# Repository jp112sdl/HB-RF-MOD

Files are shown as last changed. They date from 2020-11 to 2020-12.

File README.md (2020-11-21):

# HB-RF-MOD
Alternative Platine zum RPI-RF-MOD, um das Funkmodul "richtig herum" auf den Raspberry Pi aufsetzen zu können.

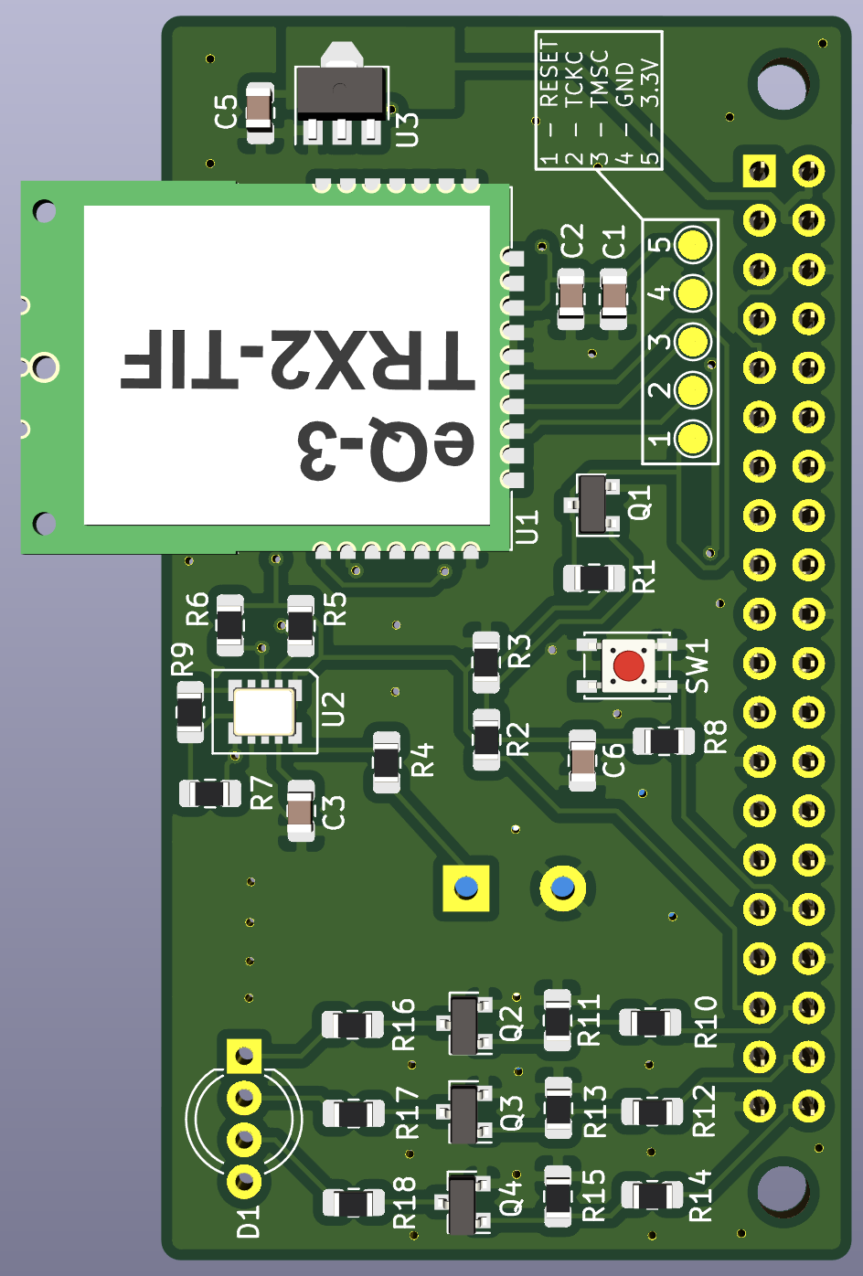
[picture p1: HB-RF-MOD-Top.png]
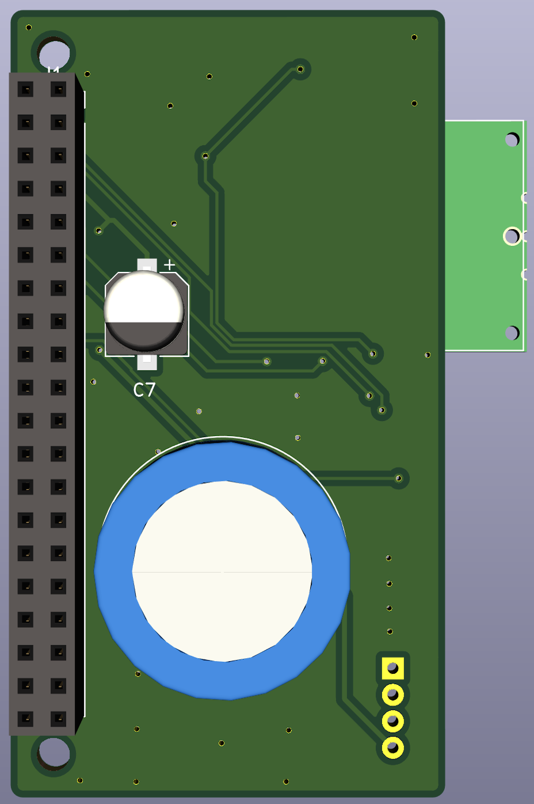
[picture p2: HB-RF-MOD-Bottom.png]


**19.11.2020 - die Platinen sind da** <br>
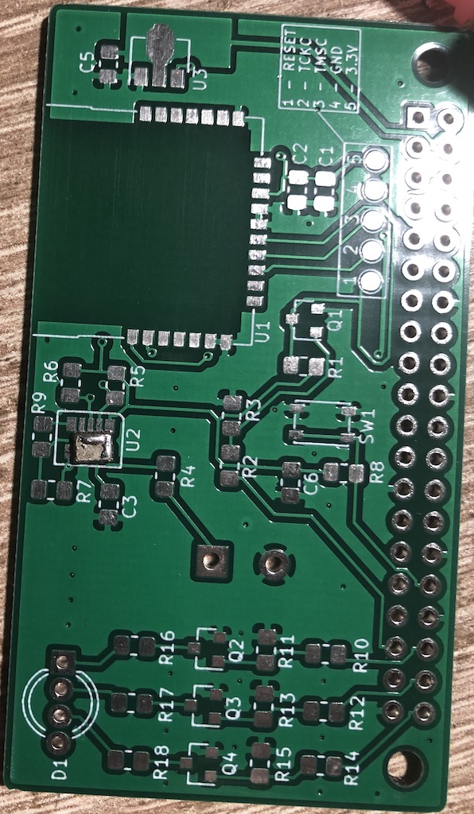
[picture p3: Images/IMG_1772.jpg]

<br/><br/>
**20.11.2020 - erster Aufbau und voller Erfolg!** :tada: <br/>
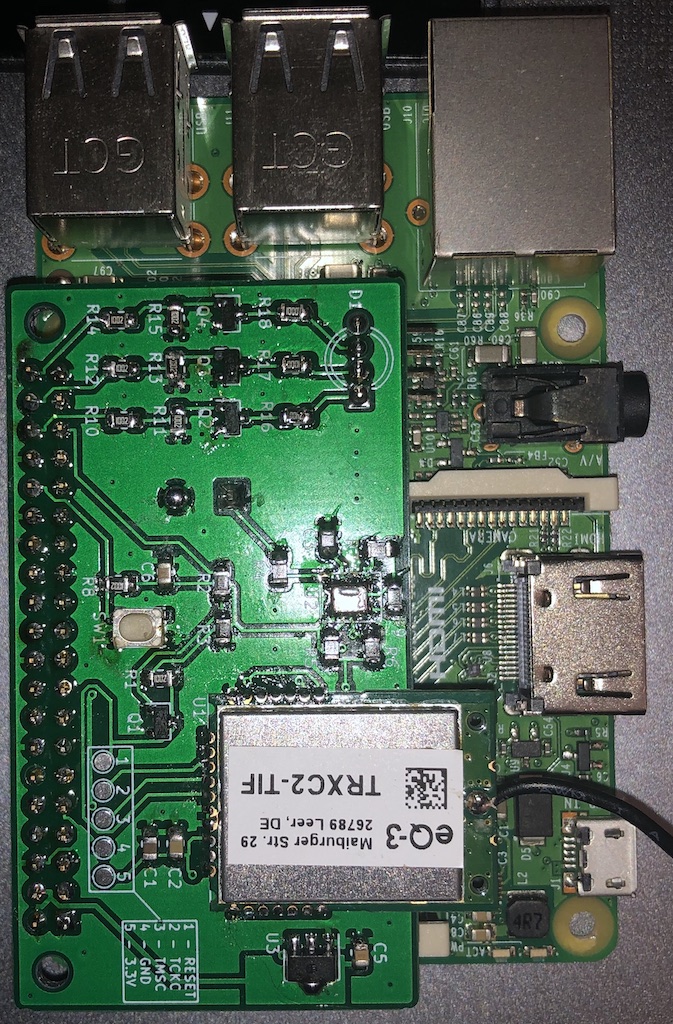
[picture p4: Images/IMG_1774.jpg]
<br/>
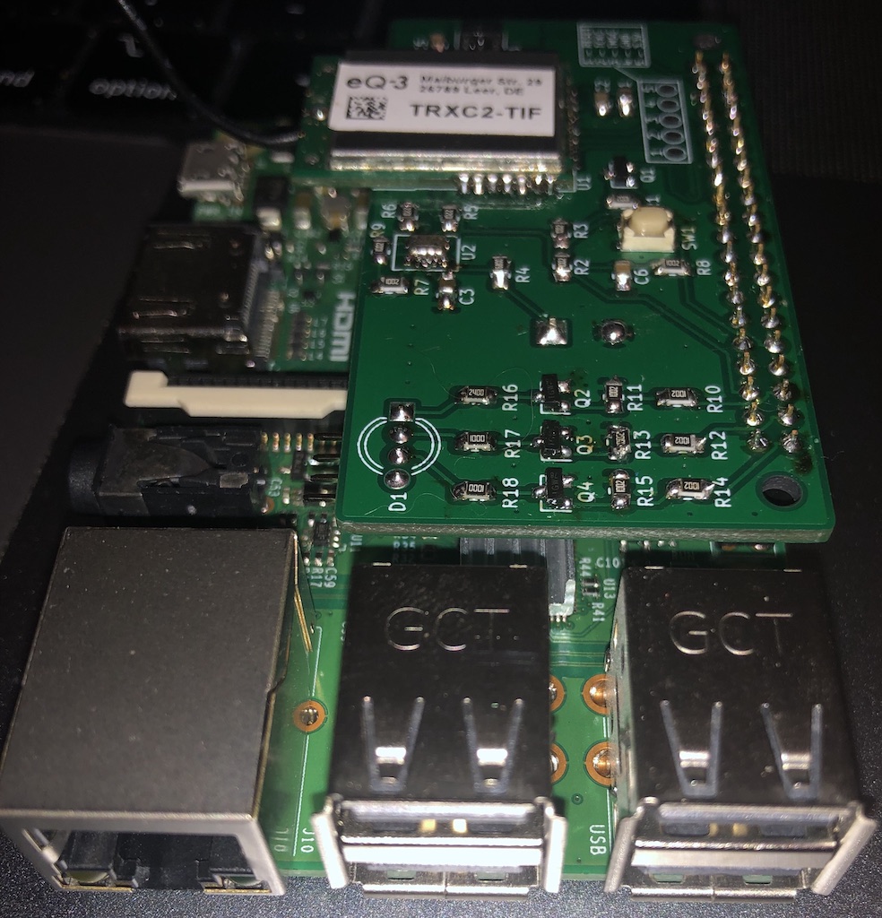
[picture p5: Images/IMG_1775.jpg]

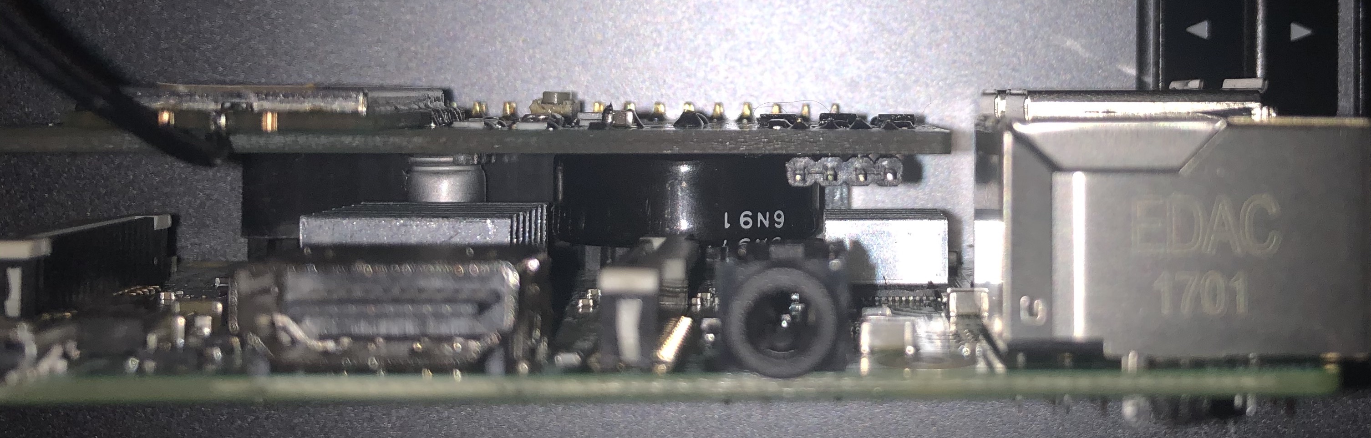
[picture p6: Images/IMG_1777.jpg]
<br/>
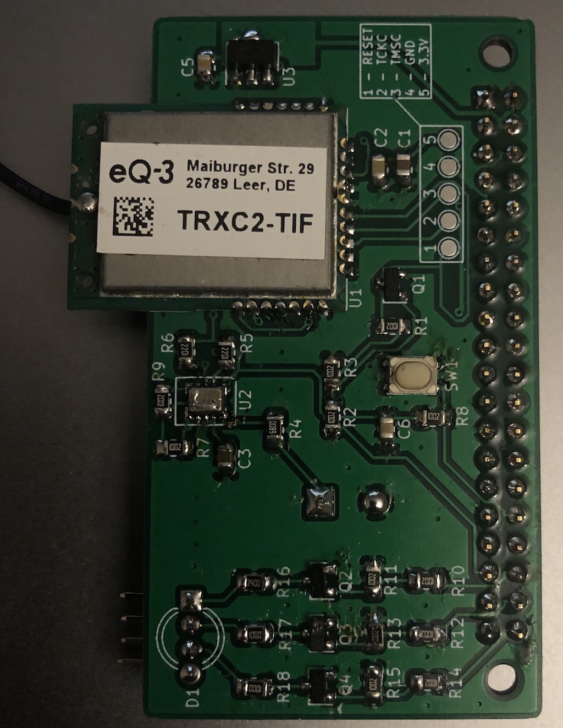
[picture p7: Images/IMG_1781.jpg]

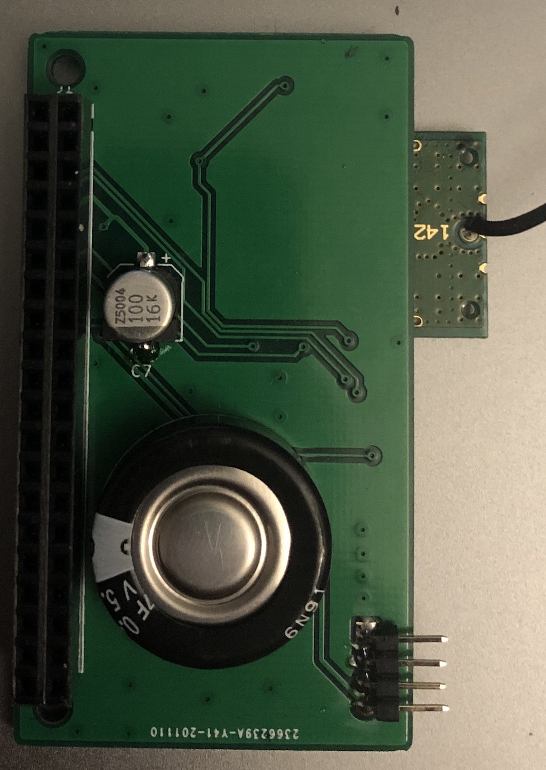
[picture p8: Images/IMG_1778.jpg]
<br/>

**21.11.2020 - Inbetriebnahme**<br/>
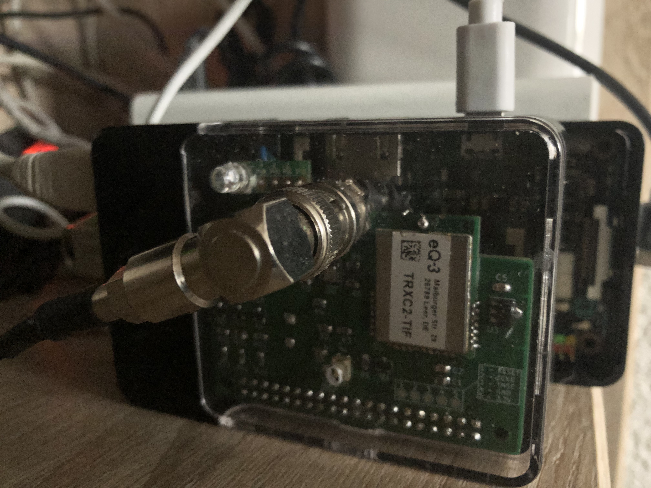
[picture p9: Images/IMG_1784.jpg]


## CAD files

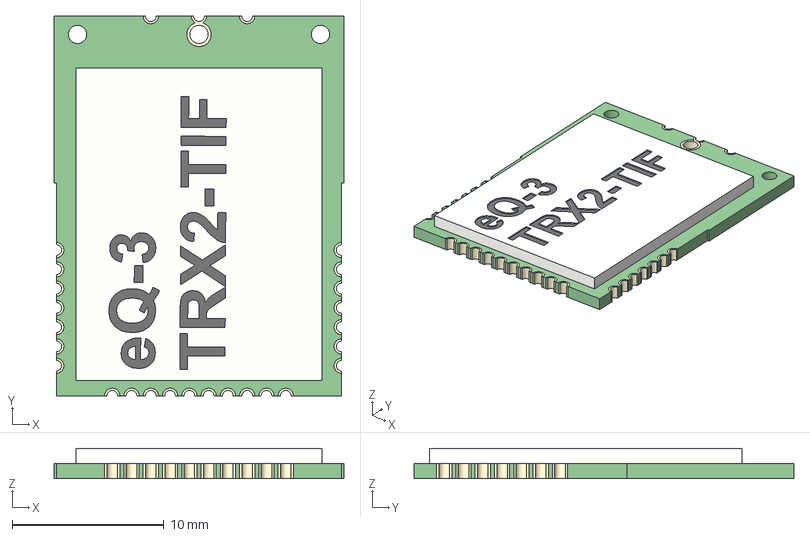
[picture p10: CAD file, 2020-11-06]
additional/TRX2-TIF.step
19.1 x 25.0 x 2.00 mm

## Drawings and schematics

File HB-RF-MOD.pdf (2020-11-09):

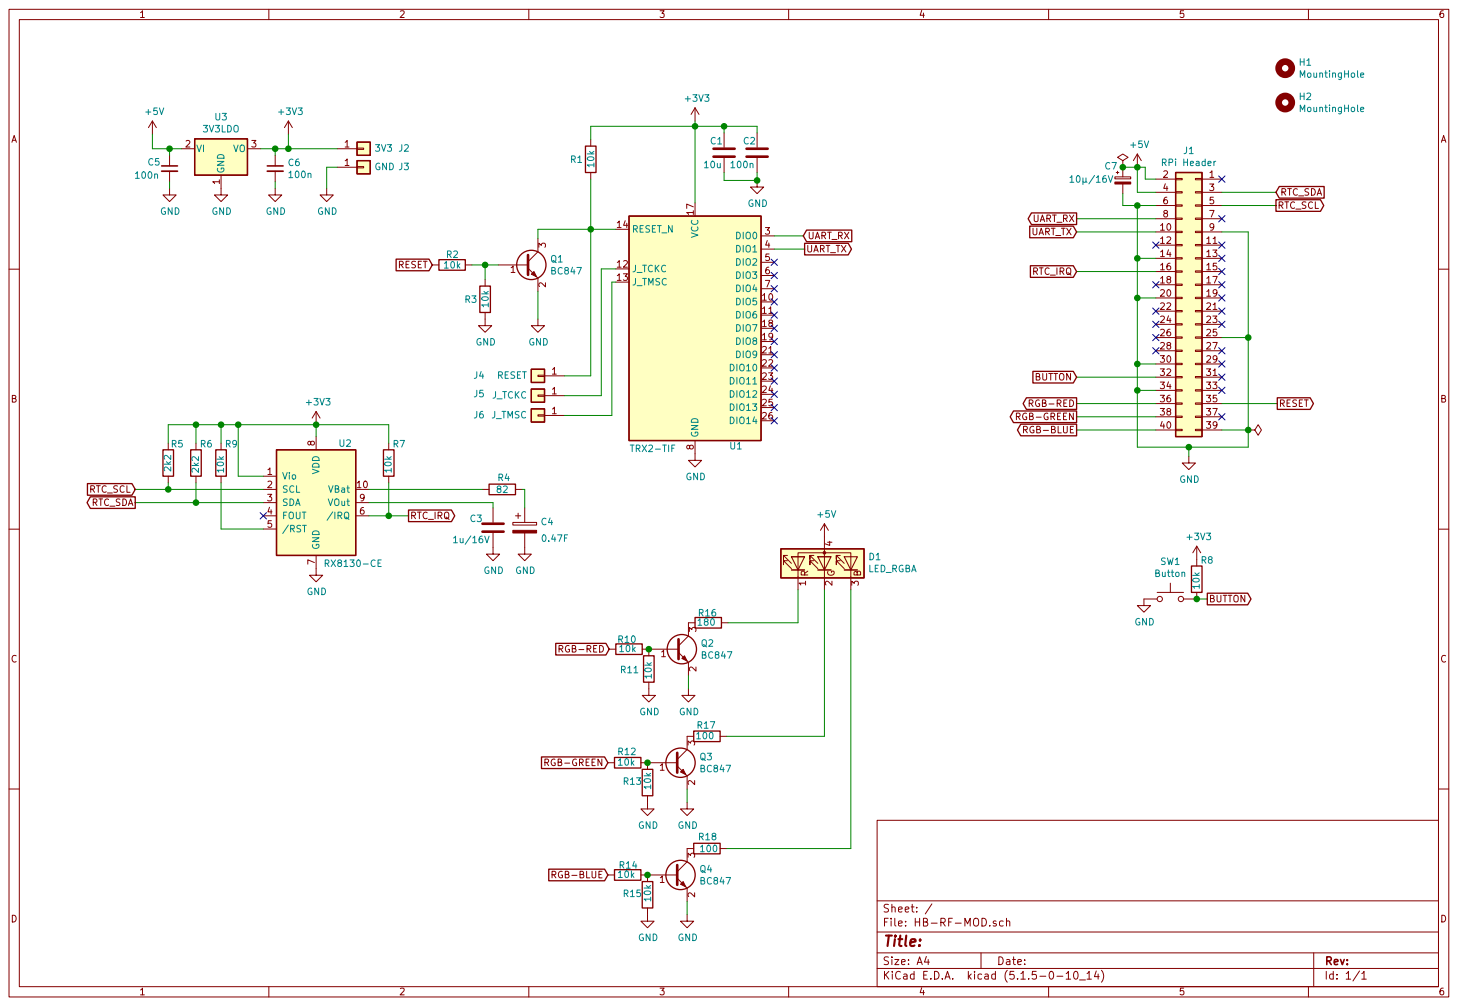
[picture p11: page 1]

Id: 1/1 Title: File: HB-RF-MOD.sch Sheet: /

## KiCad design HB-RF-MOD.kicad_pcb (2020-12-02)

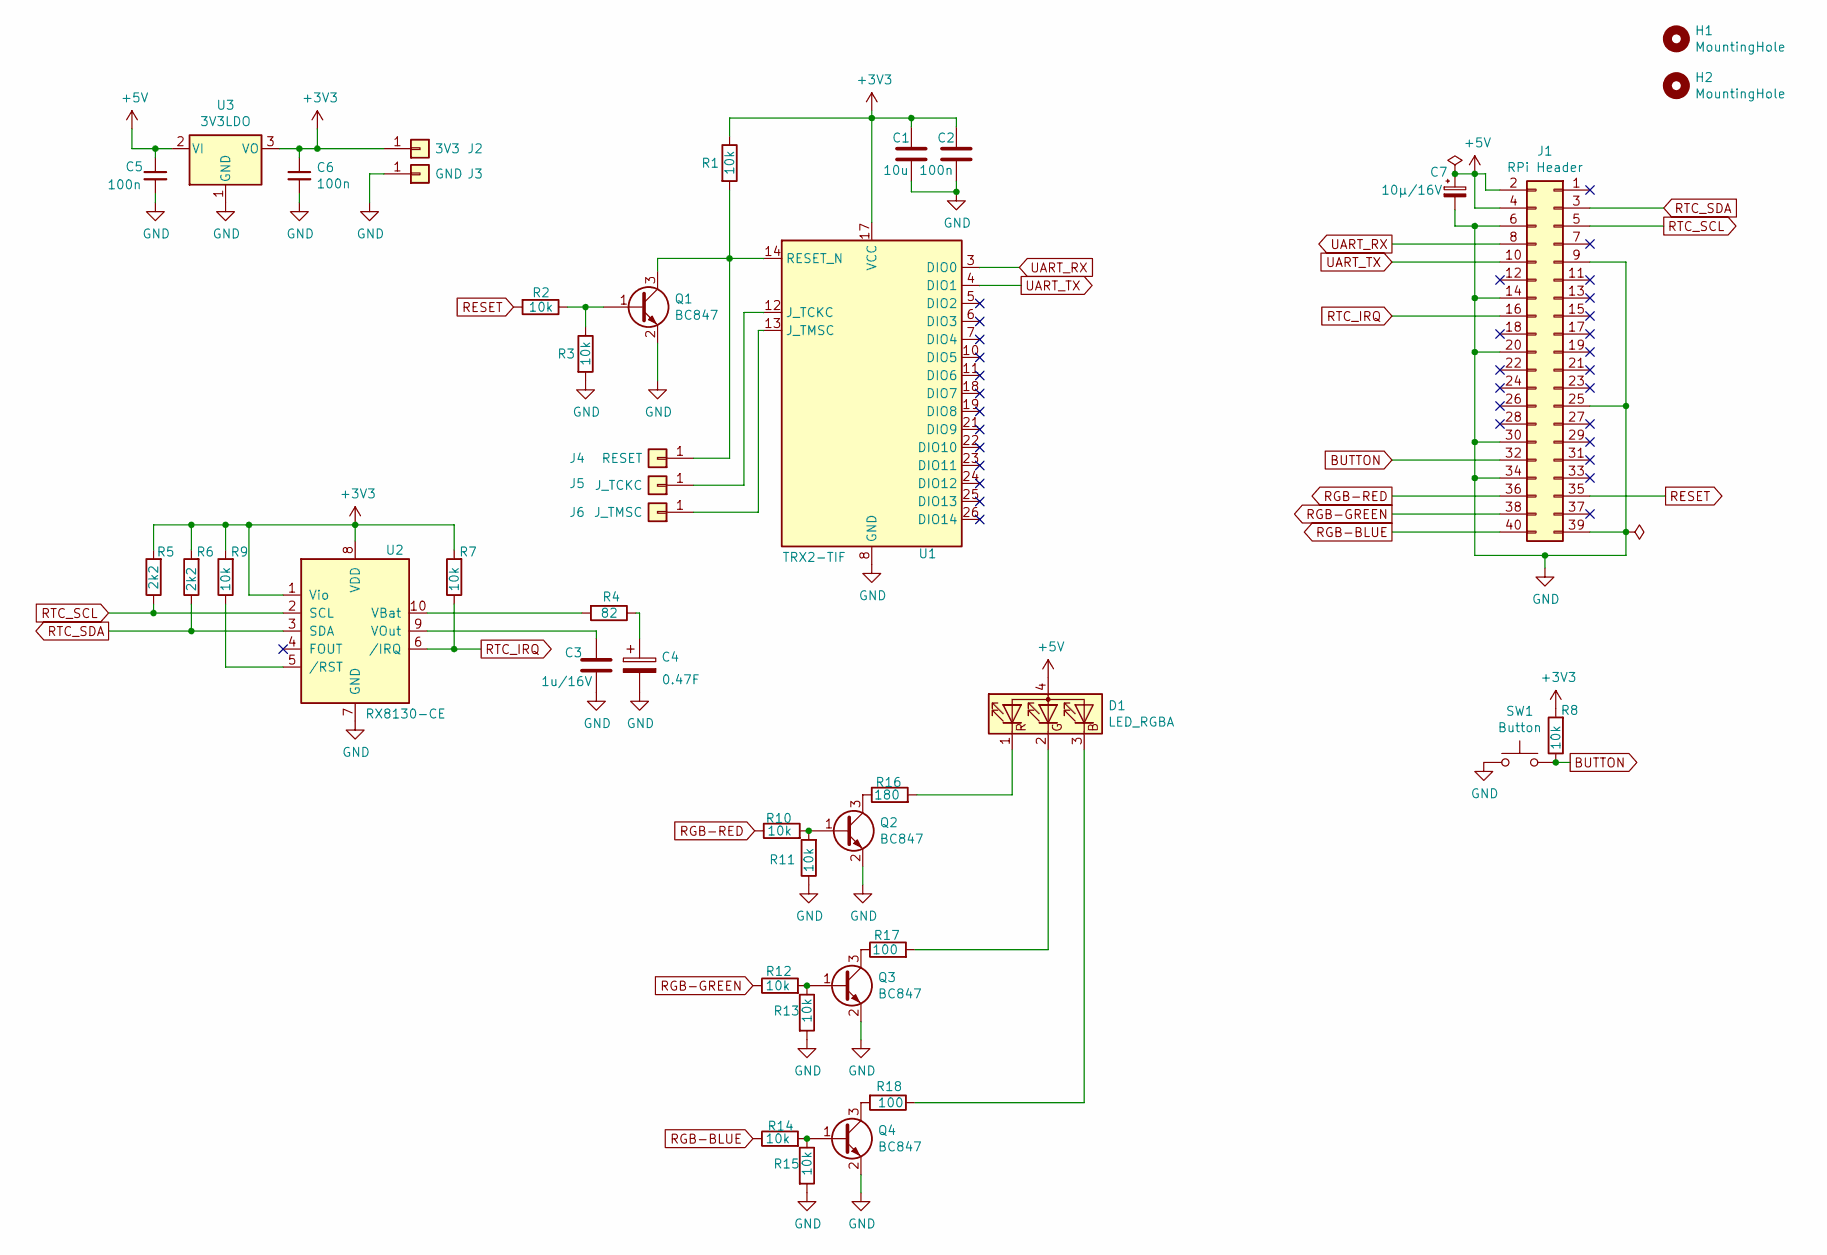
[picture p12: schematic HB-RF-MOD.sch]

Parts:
C1: 10u; C_0805_2012Metric_Pad1.15x1.40mm_HandSolder
C2, C5, C6: 100n; C_0805_2012Metric_Pad1.15x1.40mm_HandSolder
C3: 1u/16V; C_0805_2012Metric_Pad1.15x1.40mm_HandSolder
C4: 0.47F; CP_Radial_D20.0mm_P5.00mm
C7: 10µ/16V; CP_Elec_6.3x5.9
D1: LED_RGBA; LED_D5.0mm-4_RGB_Wide_Pins
H1, H2: MountingHole; MountingHole_2.7mm_M2.5_DIN965
J1: RPi Header; PinSocket_2x20_P2.54mm_Vertical
J2: 3V3; TestPoint_Pad_D1.5mm
J3: GND; TestPoint_Pad_D1.5mm
J4: RESET; TestPoint_Pad_D1.5mm
J5: J_TCKC; TestPoint_Pad_D1.5mm
J6: J_TMSC; TestPoint_Pad_D1.5mm
Q1, Q2, Q3, Q4: BC847; SOT-23
R1, R2, R3, R7, R8, R9, R10, R11, R12, R13, R14, R15: 10k; R_0805_2012Metric_Pad1.15x1.40mm_HandSolder
R4: 82; R_0805_2012Metric_Pad1.15x1.40mm_HandSolder
R5, R6: 2k2; R_0805_2012Metric_Pad1.15x1.40mm_HandSolder
R16: 180; R_0805_2012Metric_Pad1.15x1.40mm_HandSolder
R17, R18: 100; R_0805_2012Metric_Pad1.15x1.40mm_HandSolder
SW1: Button; SW_SPST_PTS810
U1: TRX2-TIF
U2: RX8130-CE; SMD-3225-10Pin_3.2x2.5mm_HandSoldering
U3: 3V3LDO; SOT-89-3

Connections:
+3V3: C1.1, C2.1, C6.1, J2.1, R1.1, R5.2, R6.2, R7.2, R8.2, R9.2, U1.17 (VCC), U2.1 (Vio), U2.8 (VDD), U3.3 (VO)
+5V: C5.1, C7.1, D1.4 (A), J1.2, J1.4, U3.2 (VI)
BUTTON: J1.32, R8.1, SW1.2
GND: C1.2, C2.2, C3.2, C4.2, C5.2, C6.2, C7.2, J1.6, J1.9, J1.14, J1.20, J1.25, J1.30, J1.34, J1.39, J3.1, Q1.2 (E), Q2.2 (E), Q3.2 (E), Q4.2 (E), R3.2, R11.1, R13.2, R15.2, SW1.1, U1.8 (GND), U1.9 (GND), U1.15 (GND), U1.16 (GND), U1.20 (GND), U2.7 (GND), U3.1 (GND)
unnamed: C3.1, U2.9 (VOut)
unnamed: C4.1, R4.1
unnamed: D1.1 (RK), R16.2
unnamed: D1.2 (GK), R17.2
unnamed: D1.3 (BK), R18.1
unnamed: J4.1, Q1.3 (C), R1.2, U1.14 (RESET_N)
unnamed: J5.1, U1.12 (J_TCKC)
unnamed: J6.1, U1.13 (J_TMSC)
unnamed: Q1.1 (B), R2.1, R3.1
unnamed: Q2.1 (B), R10.2, R11.2
unnamed: Q2.3 (C), R16.1
unnamed: Q3.1 (B), R12.2, R13.1
unnamed: Q3.3 (C), R17.1
unnamed: Q4.1 (B), R14.2, R15.1
unnamed: Q4.3 (C), R18.2
unnamed: R4.2, U2.10 (VBat)
unnamed: R9.1, U2.5 (/RST)
RESET: J1.35, R2.2
RGB-BLUE: J1.40, R14.1
RGB-GREEN: J1.38, R12.1
RGB-RED: J1.36, R10.1
RTC_IRQ: J1.16, R7.1, U2.6 (/IRQ)
RTC_SCL: J1.5, R5.1, U2.2 (SCL)
RTC_SDA: J1.3, R6.1, U2.3 (SDA)
UART_RX: J1.8, U1.3 (DIO0)
UART_TX: J1.10, U1.4 (DIO1)

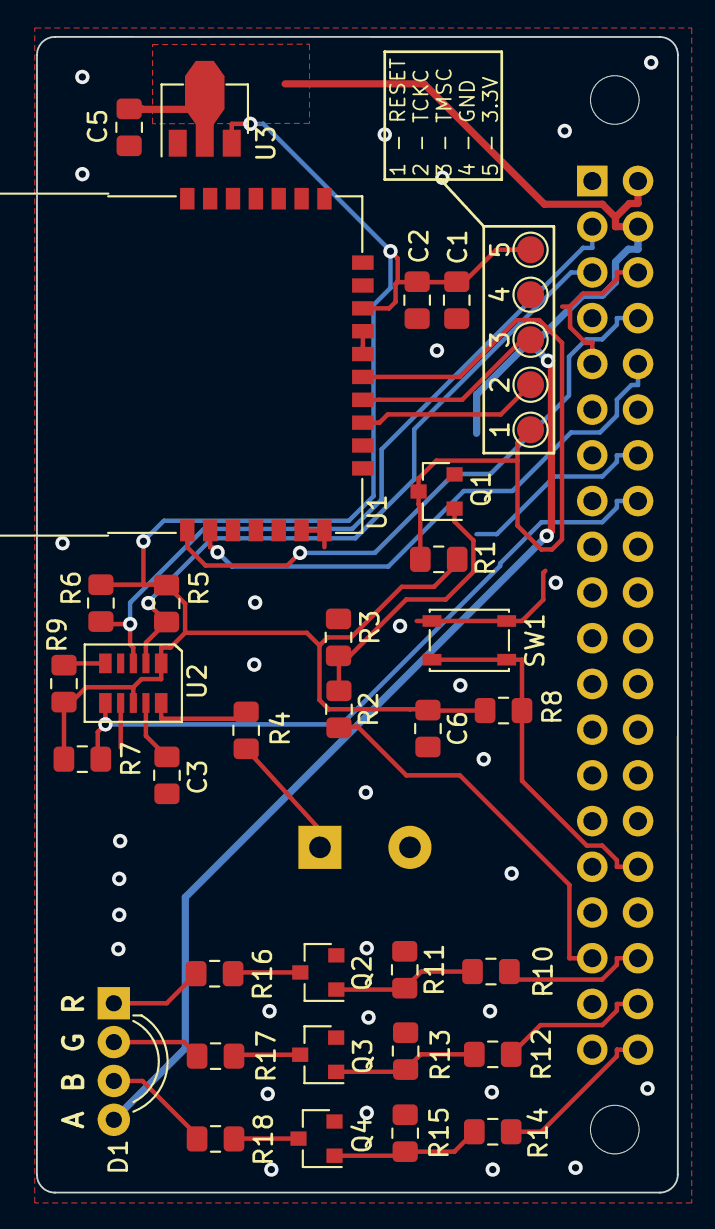
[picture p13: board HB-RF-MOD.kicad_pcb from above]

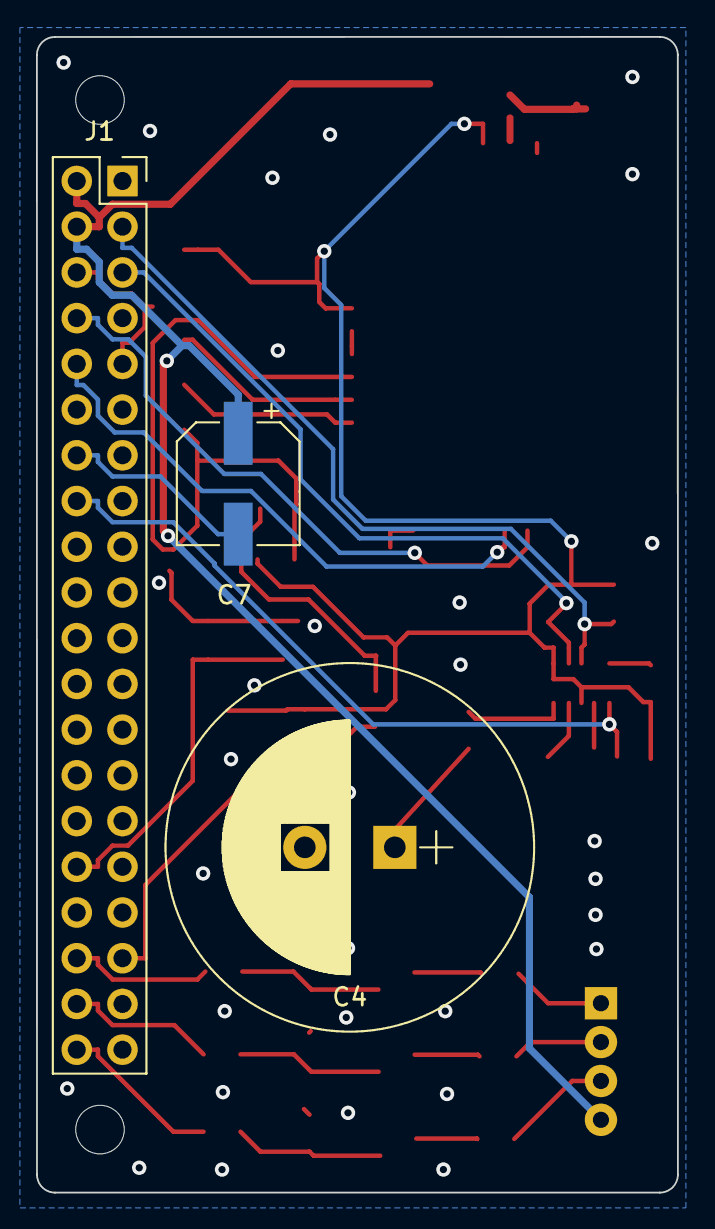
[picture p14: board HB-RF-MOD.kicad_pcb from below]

Board: 2 copper layers, 35.6 x 64.2 mm, 42 parts (3 on the bottom side), 30 nets.

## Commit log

2020-11-06 add 3D modell of TRX2-TIF
    [HB-RF-MOD.kicad_pcb, TRX2-TIF.step]
2020-11-09 update pcb
    [HB-RF-MOD-B_Cu.gbr, HB-RF-MOD-B_Mask.gbr, HB-RF-MOD-B_Paste.gbr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]
